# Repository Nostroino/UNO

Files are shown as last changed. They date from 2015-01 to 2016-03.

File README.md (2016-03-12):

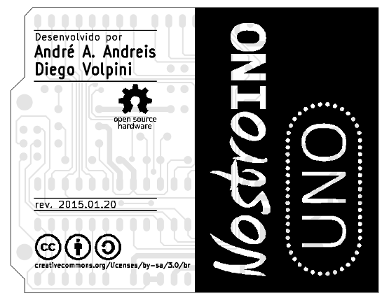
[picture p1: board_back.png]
Nostroino UNO (board back side)


Esquemático do NostroINO. [[PDF](https://github.com/nostroino/UNO/blob/master/SCH%20Nostroino%20UNO.pdf)]

No diretório [KiCad](https://github.com/nostroino/UNO/tree/master/KiCad) encontram-se todos os *Source Files* da placa disponíveis para edição. Recomenda-se utilizar a [versão 4.0.2 do KiCad](http://kicad-pcb.org/download/) ou posterior. Para faciitar dê um *Fork* em todo o diretório.

Encorajamos o uso do material disponível! Só não esqueça de atribuir crédito, como preconiza a [CC BY-SA 3.0 BR](http://creativecommons.org/licenses/by-sa/3.0/br).

Qualquer dúvida, sugestão... pode entrar em contato conosco.

Um abraço!

[_André Augusto Andreis_](<andreis.andre@gmail.com> ) e [_Diego Volpini_](<diego.volpini@gmail.com>)

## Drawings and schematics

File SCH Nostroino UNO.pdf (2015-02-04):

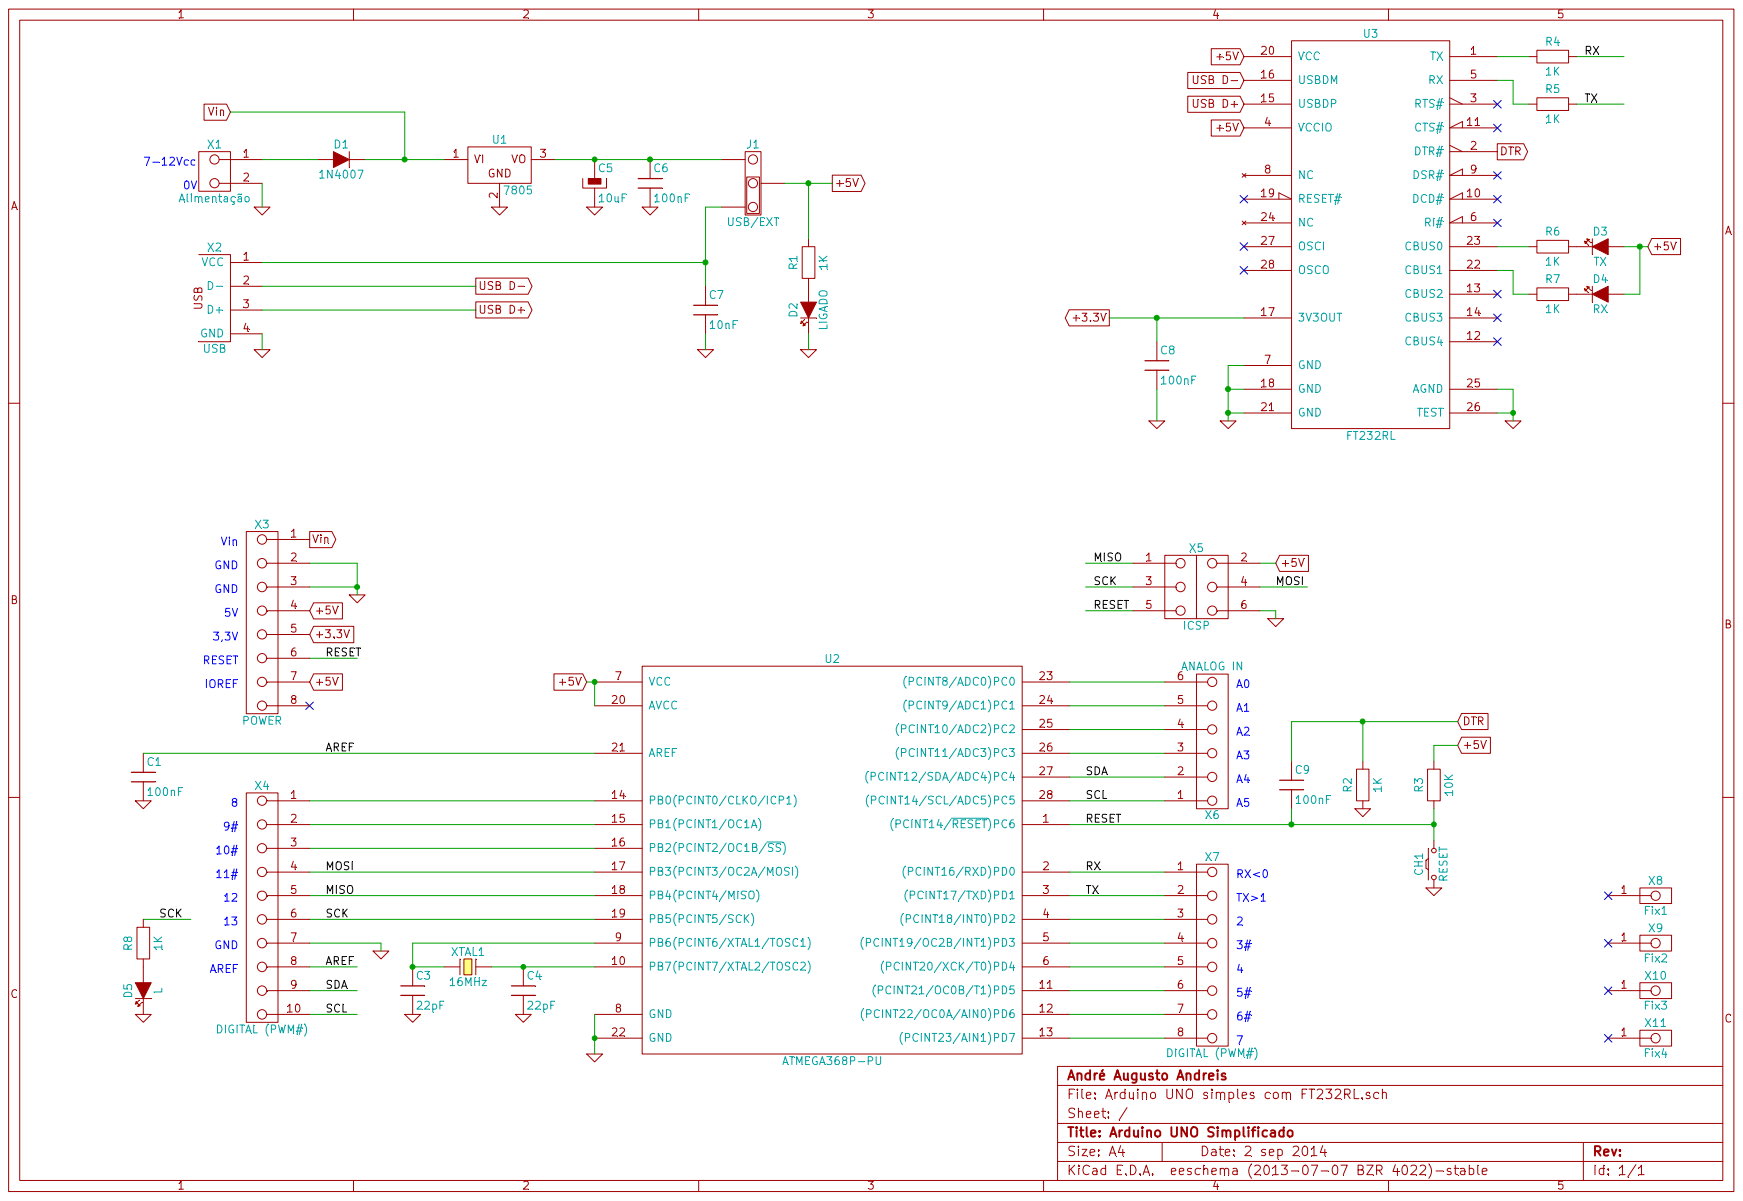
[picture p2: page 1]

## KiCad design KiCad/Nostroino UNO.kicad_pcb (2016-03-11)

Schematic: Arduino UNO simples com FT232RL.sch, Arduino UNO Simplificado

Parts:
C1, C6, C8, C9: 100nF
C3, C4: 22pF
C5: 10uF
C7: 10nF
CH1: RESET
D1: 1N4007
D2: LIGADO
D3: TX
D4: RX
D5: L
J1: USB/EXT
R1, R2, R4, R5, R6, R7, R8: 1K
R3: 10K
U1: 7805
U2: ATMEGA368P-PU
U3: FT232RL
X1: Alimentação
X2: USB
X3: POWER
X4, X7: DIGITAL (PWM#)
X5: ICSP
X6: ANALOG IN
X8: Fix1
X9: Fix2
X10: Fix3
X11: Fix4
XTAL1: 16MHz

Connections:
+3.3V: C8.1, U3.17 (3V3OUT), X3.5
+5V: D3.A (Anôdo), D4.A (Anôdo), J1.2, R1.2, R3.2, U2.7 (VCC), U2.20 (AVCC), U3.4 (VCCIO), U3.20 (VCC), X3.4, X3.7, X5.2
/AREF: C1.1, U2.21 (AREF), X4.8
/MISO: U2.18 (PB4(PCINT4/MISO)), X4.5, X5.1
/MOSI: U2.17 (PB3(PCINT3/OC2A/MOSI)), X4.4, X5.4
/RESET: C9.2, CH1.2, R3.1, U2.1 ((PCINT14/~RESET~)PC6), X3.6, X5.5
/RX: R4.2, U2.2 ((PCINT16/RXD)PD0), X7.1
/SCK: R8.2, U2.19 (PB5(PCINT5/SCK)), X4.6, X5.3
/SCL: U2.28 ((PCINT14/SCL/ADC5)PC5), X4.10, X6.1
/SDA: U2.27 ((PCINT12/SDA/ADC4)PC4), X4.9, X6.2
/TX: R5.2, U2.3 ((PCINT17/TXD)PD1), X7.2
DTR: C9.1, R2.2, U3.2 (DTR#)
GND: C1.2, C3.2, C4.2, C5.-, C6.2, C7.2, C8.2, CH1.1, D2.K (Catôdo), D5.K (Catôdo), R2.1, U1.2 (Ground), U2.8 (GND), U2.22 (GND), U3.7 (GND), U3.18 (GND), U3.21 (GND), U3.25 (AGND), U3.26 (TEST), X1.2, X2.4 (GND), X3.2, X3.3, X4.7, X5.6
unnamed: D1.A, X1.1
unnamed: C7.1, J1.3, X2.1 (VCC)
unnamed: R4.1, U3.1 (TX)
unnamed: D2.A (Anôdo), R1.1
unnamed: R5.1, U3.5 (RX)
unnamed: U2.24 ((PCINT9/ADC1)PC1), X6.5
unnamed: U2.12 ((PCINT22/OC0A/AIN0)PD6), X7.7
unnamed: U2.11 ((PCINT21/OC0B/T1)PD5), X7.6
unnamed: U2.6 ((PCINT20/XCK/T0)PD4), X7.5
unnamed: U2.5 ((PCINT19/OC2B/INT1)PD3), X7.4
unnamed: U2.4 ((PCINT18/INT0)PD2), X7.3
unnamed: U2.26 ((PCINT11/ADC3)PC3), X6.3
unnamed: U2.25 ((PCINT10/ADC2)PC2), X6.4
unnamed: U2.13 ((PCINT23/AIN1)PD7), X7.8
unnamed: U2.23 ((PCINT8/ADC0)PC0), X6.6
unnamed: U2.14 (PB0(PCINT0/CLKO/ICP1)), X4.1
unnamed: U2.16 (PB2(PCINT2/OC1B/~SS~)), X4.3
unnamed: U2.15 (PB1(PCINT1/OC1A)), X4.2
unnamed: D5.A (Anôdo), R8.1
unnamed: R7.1, U3.22 (CBUS1)
unnamed: R6.1, U3.23 (CBUS0)
unnamed: D4.K (Catôdo), R7.2
unnamed: D3.K (Catôdo), R6.2
unnamed: C4.1, U2.10 (PB7(PCINT7/XTAL2/TOSC2)), XTAL1.2
unnamed: C3.1, U2.9 (PB6(PCINT6/XTAL1/TOSC1)), XTAL1.1
unnamed: C5.+, C6.1, J1.1, U1.3 (Output)
USB D+: U3.15 (USBDP), X2.3 (D+)
USB D-: U3.16 (USBDM), X2.2 (D-)
Vin: D1.K, U1.1 (Input), X3.1

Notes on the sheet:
7-12Vcc
10#
11#
GND
AREF
Vin
3,3V
RESET
IOREF
RX<0
TX>1

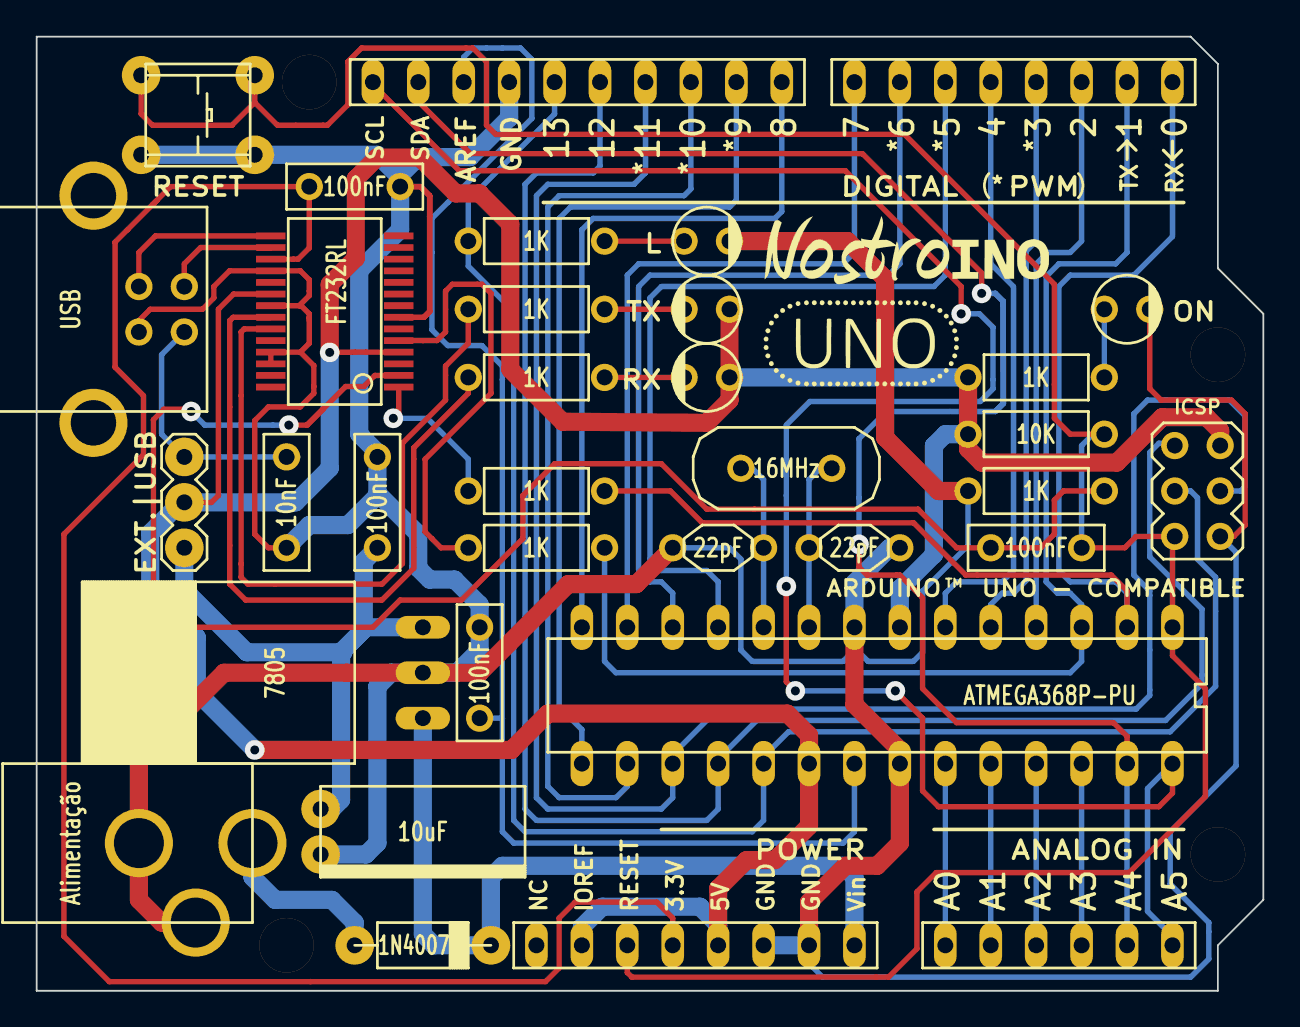
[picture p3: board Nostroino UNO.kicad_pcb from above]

Board: 2 copper layers, 68.6 x 53.3 mm, 45 parts (0 on the bottom side), 42 nets.

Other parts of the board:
VAL: REF; OSHW-logo_B.SilkS_8mm_flipped
VAL#2: REF; CC-logo_B.SilkS_5mm_flipped
VAL#3: REF; BY-logo_B.SilkS_5mm_flipped
VAL#4: REF; SA-logo_B.SilkS_5mm_flipped
VAL#5: REF; UNO-logo_F.SilkS_11mm
VAL#6: REF; Nostroino-logo_F.SilkS_16mm
VAL#7: REF; Nostroino_UNO-logo_B.SilkS_34.29mm_flipped

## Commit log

2015-01-27 KiCad Files
    [Arduino UNO simples com FT232RL.sch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]
2015-01-27 Rename Folders
    [Arduino UNO simples com FT232RL_2-B_Cu.gbl, Arduino UNO simples com FT232RL_2-B_Mask.gbs, Arduino UNO simples com FT232RL_2-B_SilkS.gbo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]
2015-02-04 Update Silk PCB
    [Nostroino UNO.kicad_pcb, Nostroino UNO.sch]
2015-02-04 Silks Updates
    [Nostroino UNO-B_Cu.gbl, Nostroino UNO-B_Mask.gbs, Nostroino UNO-B_SilkS.gbo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]
2015-02-04 Schematic Nostroino UNO [pdf]
2015-02-05 KiCad PCB Updat
    - GND USB passando para trilha 1A;
    - N-000004 passando para trilha 1A;
    - Sinal “+” no footprint no Cap. 10uF;
    - Aumentar furos do “EXT./USB” e ICSP;
    - Atualização Board Version para 2015.02.05.
    [Nostroino UNO.kicad_pcb]
2015-02-05 KiCad
    Adição de Zonas F. Cu e B. Cu
    [Nostroino UNO.kicad_pcb]
2016-03-11 Update to KiCad 4.0.2
    [Nostroino UNO.kicad_pcb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]
